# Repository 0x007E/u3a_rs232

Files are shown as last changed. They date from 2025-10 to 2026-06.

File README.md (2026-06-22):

  

# `U3A_rs232` - RS232 - Adapter for U3A



The `U3A_rs232` project is based on a ([MAX3232](#additional-information)) that ist used to change the TTL/CMOS level to the required level of TIA/EIA-232-F standard. It can simply be adapted to the [U3A-Module](https://github.com/0x007e/u3a). The Module can be used with a [DSUB](https://www.reichelt.de/de/de/shop/produkt/d-sub-stecker_9-pol_flachbandkabel_ohne_isolator-6987) connector.

> To use it with a [DSUB](https://www.reichelt.de/de/de/shop/produkt/d-sub-stecker_9-pol_flachbandkabel_ohne_isolator-6987) connector it is necessary to create a connector cable that can be plugged into the IDC connector.

| Experience | Level |
|:---|:-----:|
| Soldering | ?% |
| Mechanical  | ?% |

# Downloads

| Type | File | Description |
|:---:|:---:|:---|
| Schematic | [pdf](https://github.com/0x007E/u3a_rs232/releases/latest/download/schematic.pdf) / [cadlab](https://cadlab.io/project/29701/main/files) | Schematic files |
| Board | [pdf](https://github.com/0x007E/u3a_rs232/releases/latest/download/pcb.pdf) / [cadlab](https://cadlab.io/project/29701/main/files) | Board file |
| Drill | [pdf](https://github.com/0x007E/u3a_rs232/releases/latest/download/drill.pdf) | Drill file |
| BoM | [xlsx](https://github.com/0x007E/u3a_rs232/releases/latest/download/bom.xlsx) / [html](https://github.com/0x007E/u3a_rs232/releases/latest/download/ibom.html) | Bill of Material as Excel/interactive HTML |
| PCB | [zip](https://github.com/0x007E/u3a_rs232/releases/latest/download/kicad.zip) / [tar](https://github.com/0x007E/u3a_rs232/releases/latest/download/kicad.tar.gz) | KiCAD/Gerber/BoM/Drill files |
| Mechanical | [zip](https://github.com/0x007E/u3a_rs232/releases/latest/download/freecad.zip) / [tar](https://github.com/0x007E/u3a_rs232/releases/latest/download/freecad.tar.gz) | FreeCAD/Housing and PCB (STEP/STL) files |

# Hardware

There are two parts of the hardware. The pcb and the housing of the `U3A_rs232`. The pcb is created with [KiCAD](#additional-information) and the housing with [FreeCAD](#additional-information). All files are built with `github actions` so that they are ready for a production environment. The housing is printed with a 3D-printer (`Dremel 3D40`).

## PCB

The circuit board is populated on both sides (Top, Bottom). The best way for soldering the `SMD` components is within a vapor phase soldering system and for the `THT` components with a standard soldering system.

### Top Layer

Top Layer

### Bottom Layer

Bottom Layer

## Mechanical

The housing has a tolerance of `0.2mm` on each side of the case. So the pcb should fit perfectly in the housing. The tolerance can be modified with `FreeCAD` in the `Parameter` Spreadsheet.

### Assembled

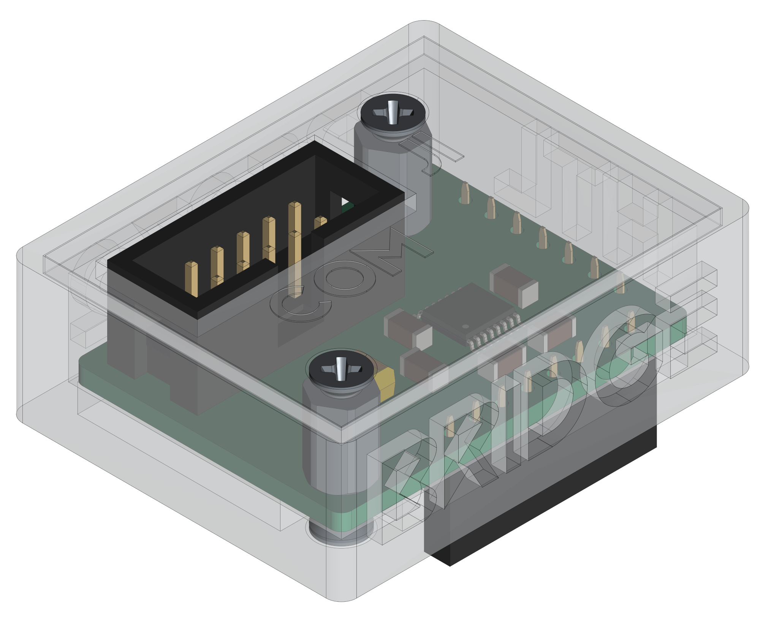
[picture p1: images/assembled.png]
Assembled


#### Exploded

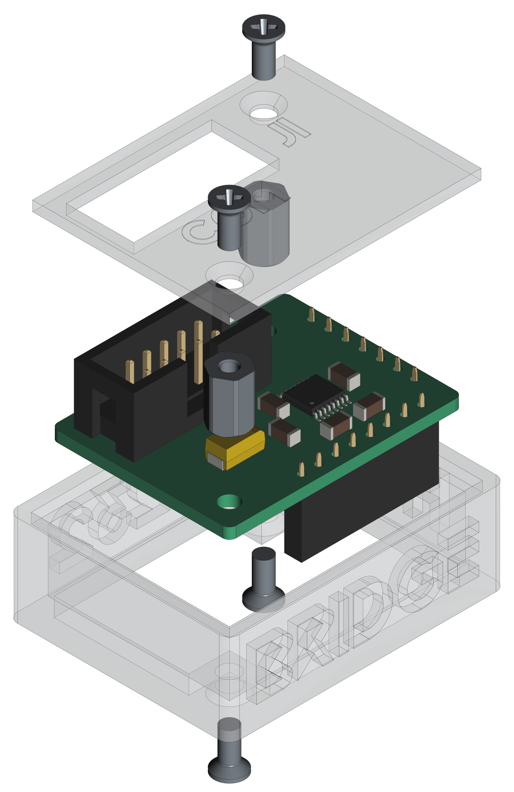
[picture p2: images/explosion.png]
Exploded


# Connection/Setup

The `U3A_rs232` is powerd over the `U3A` board with `5V`. The voltage of the pins are driven by a `MAX3232` that creates its own voltage for data transmission that meets the TIA/EIA-232-F standard.

## Simple loopback setup for testing purpose

``` bash
#
#            +--------------------------------+           +-----------------------------------+      +---------------------+
#            |                              J2|           |J2     U                       +---+---+  |                     |
#            | J1         U3A_rs232        +--+--+     +--+--+    S                U      |  USB  |--+ +-----------------+ |
#         +--+--+                          | VCC +-----+ VCC |    B      UPDI      3      +---+---+  | | TeraTerm        | |
#         + GND | (5)                      | GND +-----+ GND |    /    +---+---+   A          |      | | ~~~~~~~~        | |
#         +-----+                          |  X  +-----| PDI |    U    |   |   |              |      | | ~~~~~           | |
#   L     + CTS | (8)                      | CTS +-----+ CTS |    A    |   |   |              |      | | ~~~~~~~~~~~~    | |
#   O     + RTS | (7)                      | RTS +-----+ RTS |    R    | X | X |              |      | |                 | |
#   O +---+ TXD | (3)                      | TXD +-----+ TXD |    T    +---+---+     +-+      |      | +-----------------+ |
#   P +---+ RXD | (2)                      | RXD +-----+ RXD |    /                 / /       |      |                     |
#   B     +--+--+                          +--+--+     +--+--+    U               +-+-+-+-+-+-+      | Computer            |
#   A        |                                |           |       P               | 5V  | 3V3 |      |                     |
#   C        |                                |           |       D               +-----+-----+      +---------------------+
#   K        |                                |           |       I         J4                |
#            |                                |           | +---+---+---+---+---+---+---+---+ |
#            |                                |           | | V | C | C | D | D | D | R | G | |
#            |                                |           +-+ C | B | B | C | T | C | I | N +-+
#            |                                |             | C | 3 | 2 | D | R | R |   | D |
#            +--------------------------------+             +---+---+---+---+---+---+---+---+
```

# Additional Information

| Type | Link | Description |
|:---:|:---:|:---|
| MAX3232 | [pdf](https://www.ti.com/lit/ds/symlink/max3232e-q1.pdf) | UART / RS232 level converter |
| KiCAD | [web](https://www.kicad.org/) | KiCAD project page |
| FreeCAD | [web](https://www.freecad.org/) | FreeCAD project page |

---

R. GAECHTER

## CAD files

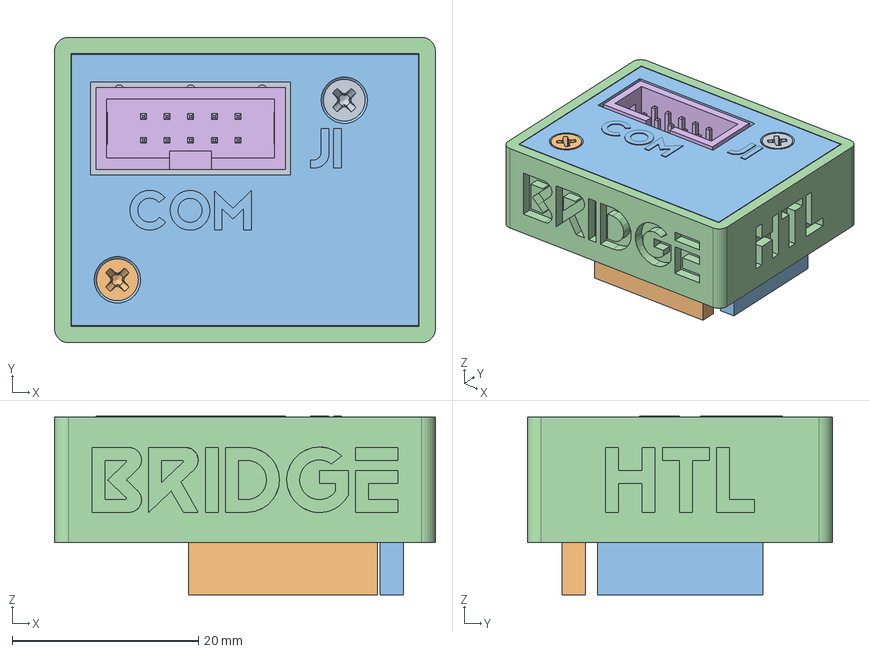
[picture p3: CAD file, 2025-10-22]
mechanical/housing.FCStd
40.9 x 32.8 x 19.2 mm
Pcb_48e6
C3_C_1206_3216Metric_502a56732e2b
C1_CP_EIA_6032_28_Kemet_C_5b3d048b5700
C6_C_1206_3216Metric_28786ebfbb54
C5_C_1206_3216Metric_dfe55a65aafe
J1_IDC_Header_2x05_P254mm_Vertical_b8abcef818d7
C2_C_1206_3216Metric_facdef2fd234
C4_C_1206_3216Metric_b65c68d2b1f9
U1_TSSOP-16_4.4x5mm_P0.65mm_098a6dea6600
J4_PinSocket_1x08_P2.54mm_Vertical_36e3868fe61d
J2_PinSocket_1x07_P2.54mm_Vertical_e5fd038025c4
Case
M2.5x7.5x5-Spacer
M2.5x7.5x5-Spacer001
M2.5x8-Screw
M2.5x8-Screw001
M2.5x4-Screw
M2.5x4-Screw001
Acrylglass

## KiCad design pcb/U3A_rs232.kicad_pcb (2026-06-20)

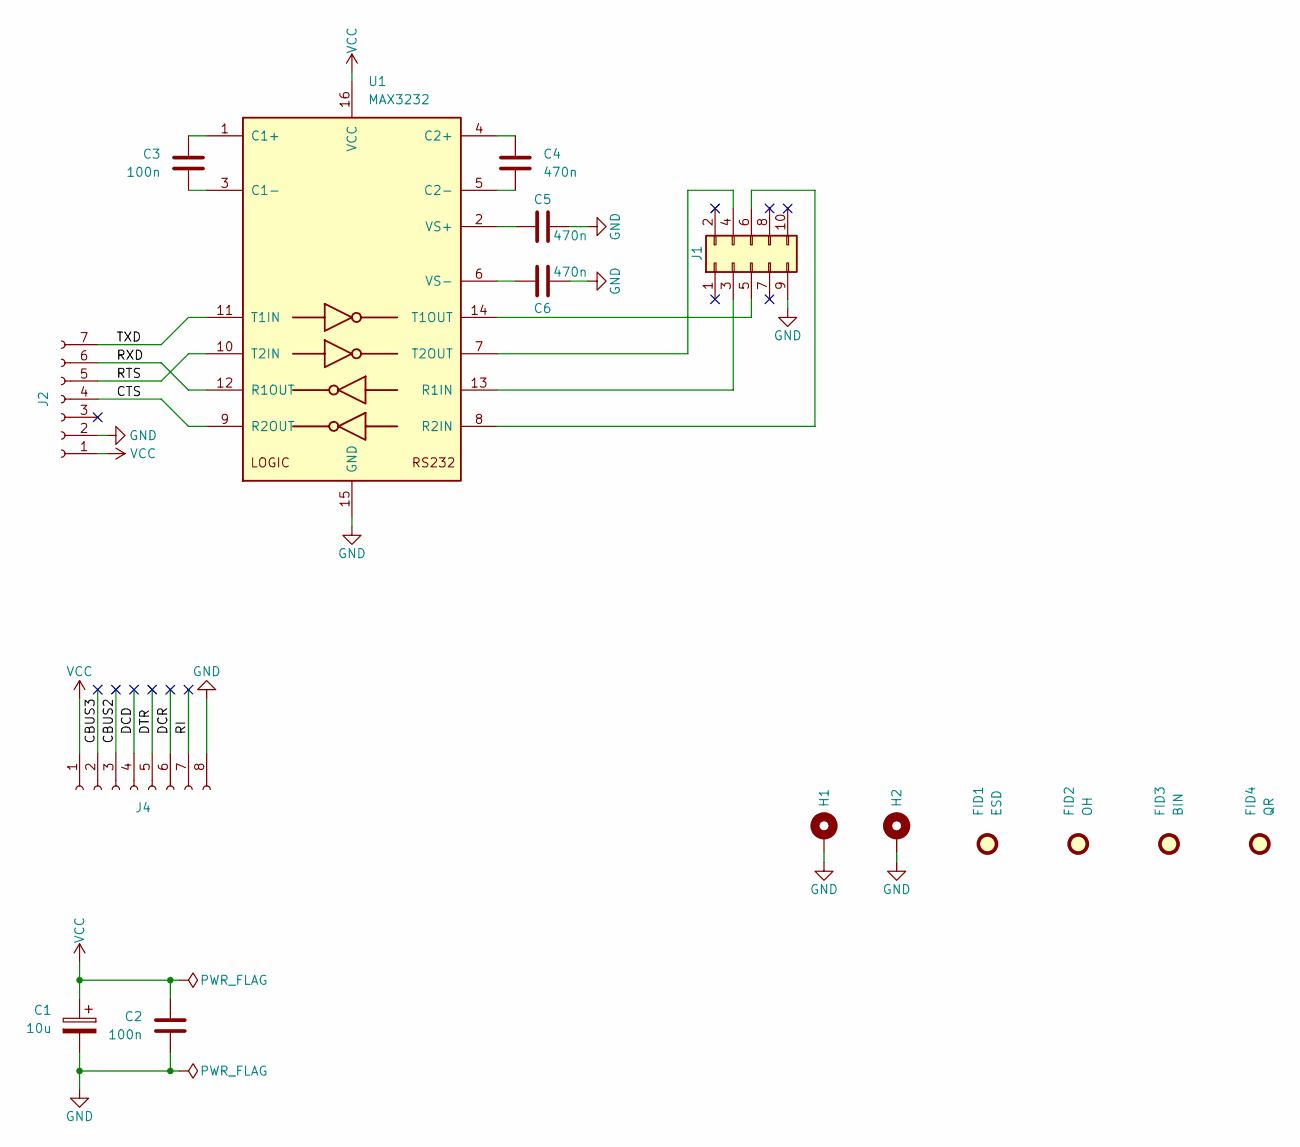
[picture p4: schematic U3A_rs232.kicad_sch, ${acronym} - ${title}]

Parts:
C1: 10u; CP_EIA-6032-28_Kemet-C
C2, C3: 100n; C_1206_3216Metric
C4, C5, C6: 470n; C_1206_3216Metric
FID1: ESD; ESD-Logo_6.6x6mm_SilkScreen
FID2: OH; OSHW-Logo_5.7x6mm_SilkScreen
FID3: BIN; WEEE-Logo_4.2x6mm_SilkScreen
FID4: QR; QR_0x007e
H1, H2: MountingHole_Pad; MountingHole_2.7mm_M2.5_Pad; DigiKey 732-12987-ND
J1: Conn_02x05_Odd_Even; IDC-Header_2x05_P2.54mm_Vertical
J2: Conn_01x07_Socket; PinSocket_1x07_P2.54mm_Vertical
J4: Conn_01x08_Socket; PinSocket_1x08_P2.54mm_Vertical
U1: MAX3232; TSSOP-16_4.4x5mm_P0.65mm

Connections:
/CBUS2: J4.3
/CBUS3: J4.2
/CTS: J2.4, U1.9 (R2OUT)
/DCD: J4.4
/DCR: J4.6
/DTR: J4.5
/RI: J4.7
/RTS: J2.5, U1.10 (T2IN)
/RXD: J2.6, U1.12 (R1OUT)
/TXD: J2.7, U1.11 (T1IN)
GND: C1.2, C2.1, C5.1, C6.1, H1.1, H2.1, J1.9, J2.2, J4.8, U1.15 (GND)
unnamed: J1.3, U1.13 (R1IN)
unnamed: J1.4, U1.7 (T2OUT)
unnamed: J1.5, U1.14 (T1OUT)
unnamed: J1.6, U1.8 (R2IN)
unnamed: C3.2, U1.1 (C1+)
unnamed: C3.1, U1.3 (C1-)
unnamed: C4.2, U1.4 (C2+)
unnamed: C4.1, U1.5 (C2-)
unnamed: C5.2, U1.2 (VS+)
unnamed: C6.2, U1.6 (VS-)
VCC: C1.1, C2.2, J2.1, J4.1, U1.16 (VCC)

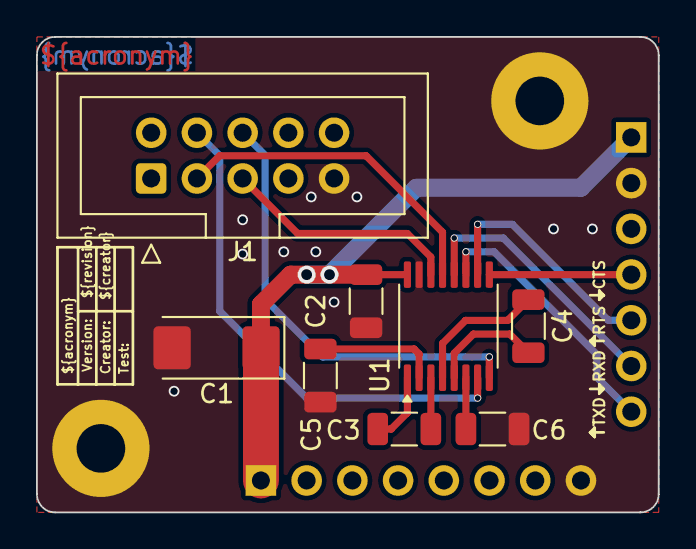
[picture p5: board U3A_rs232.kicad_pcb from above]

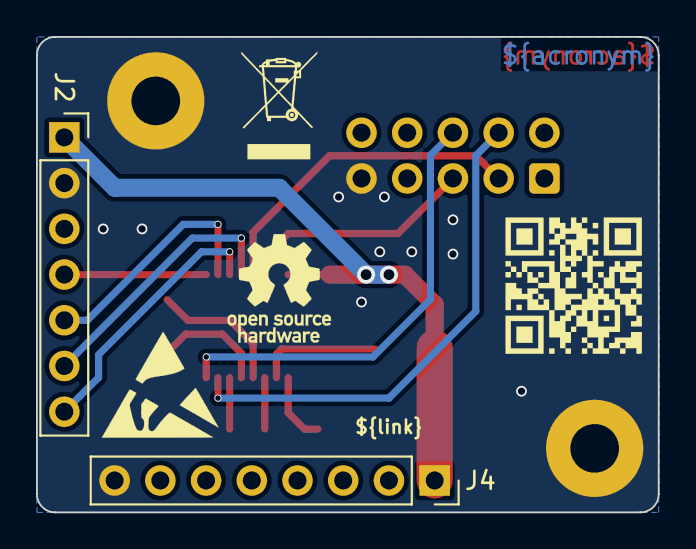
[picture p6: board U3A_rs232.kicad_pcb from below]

Board: 2 copper layers, 34.5 x 26.4 mm, 16 parts (6 on the bottom side), 16 nets.

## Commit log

2025-10-21 Adapt partlist vendors
    [U3A_rs232.kicad_pcb, U3A_rs232.kicad_sch]
2025-10-21 Fabrication layer setup
    [U3A_rs232.kicad_pcb]
2025-10-22 Adapt screw length
    [housing.FCStd]
2026-06-20 Update to KiCAD 9
    [U3A_rs232.kicad_pcb, U3A_rs232.kicad_sch]
2026-06-20 Rename/Add/Remove bom fields
    [U3A_rs232.kicad_pcb, U3A_rs232.kicad_sch]
2026-06-20 Rearrange rs232 traces
    [U3A_rs232.kicad_pcb]
2026-06-22 Add missing values in bom

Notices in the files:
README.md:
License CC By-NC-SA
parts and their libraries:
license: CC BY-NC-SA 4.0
